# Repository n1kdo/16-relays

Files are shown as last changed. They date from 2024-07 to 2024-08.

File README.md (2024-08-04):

# 16-relays

This is a board that allows a Raspberry Pi Pico-W to control 16 SPST relays.

The original purpose is to provide better automation for a 2-in, 6-out remote antenna switch, but
it is built with extra capacity to allow a 2-in, 8-out remote switch as well.

## 3D image from KiCad
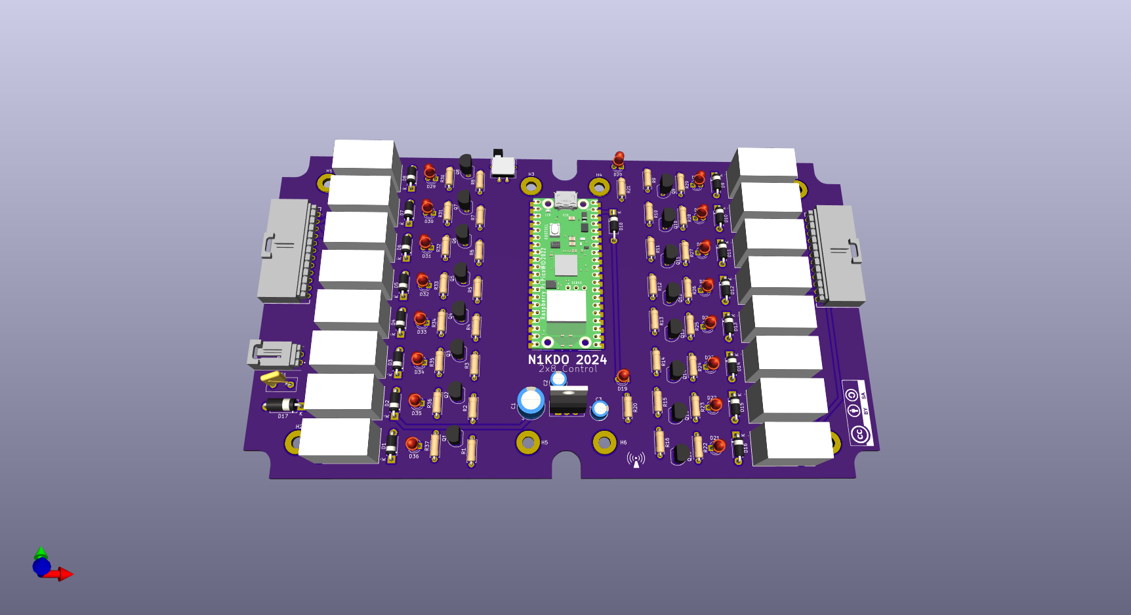
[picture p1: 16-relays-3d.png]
3d image


## Real World Image

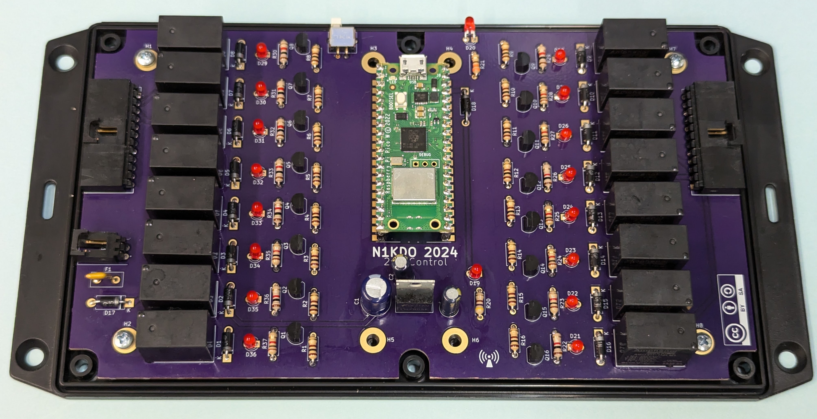
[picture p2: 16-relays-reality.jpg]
Real-World Image


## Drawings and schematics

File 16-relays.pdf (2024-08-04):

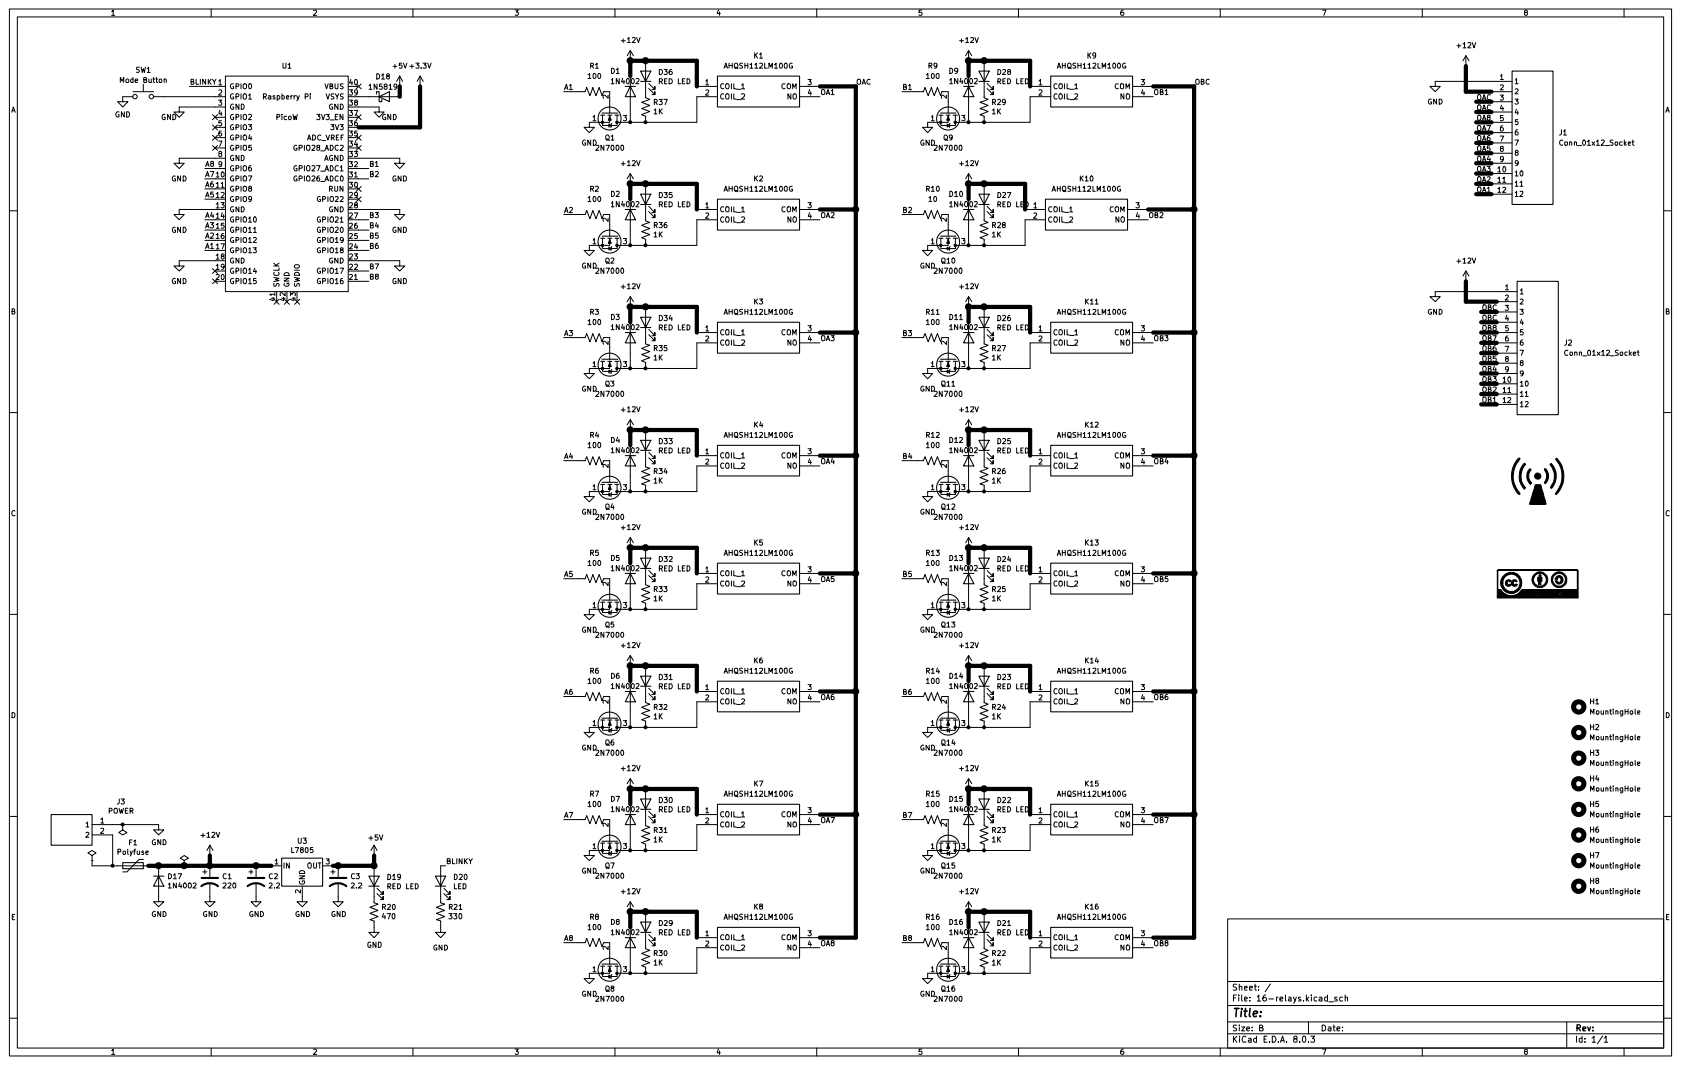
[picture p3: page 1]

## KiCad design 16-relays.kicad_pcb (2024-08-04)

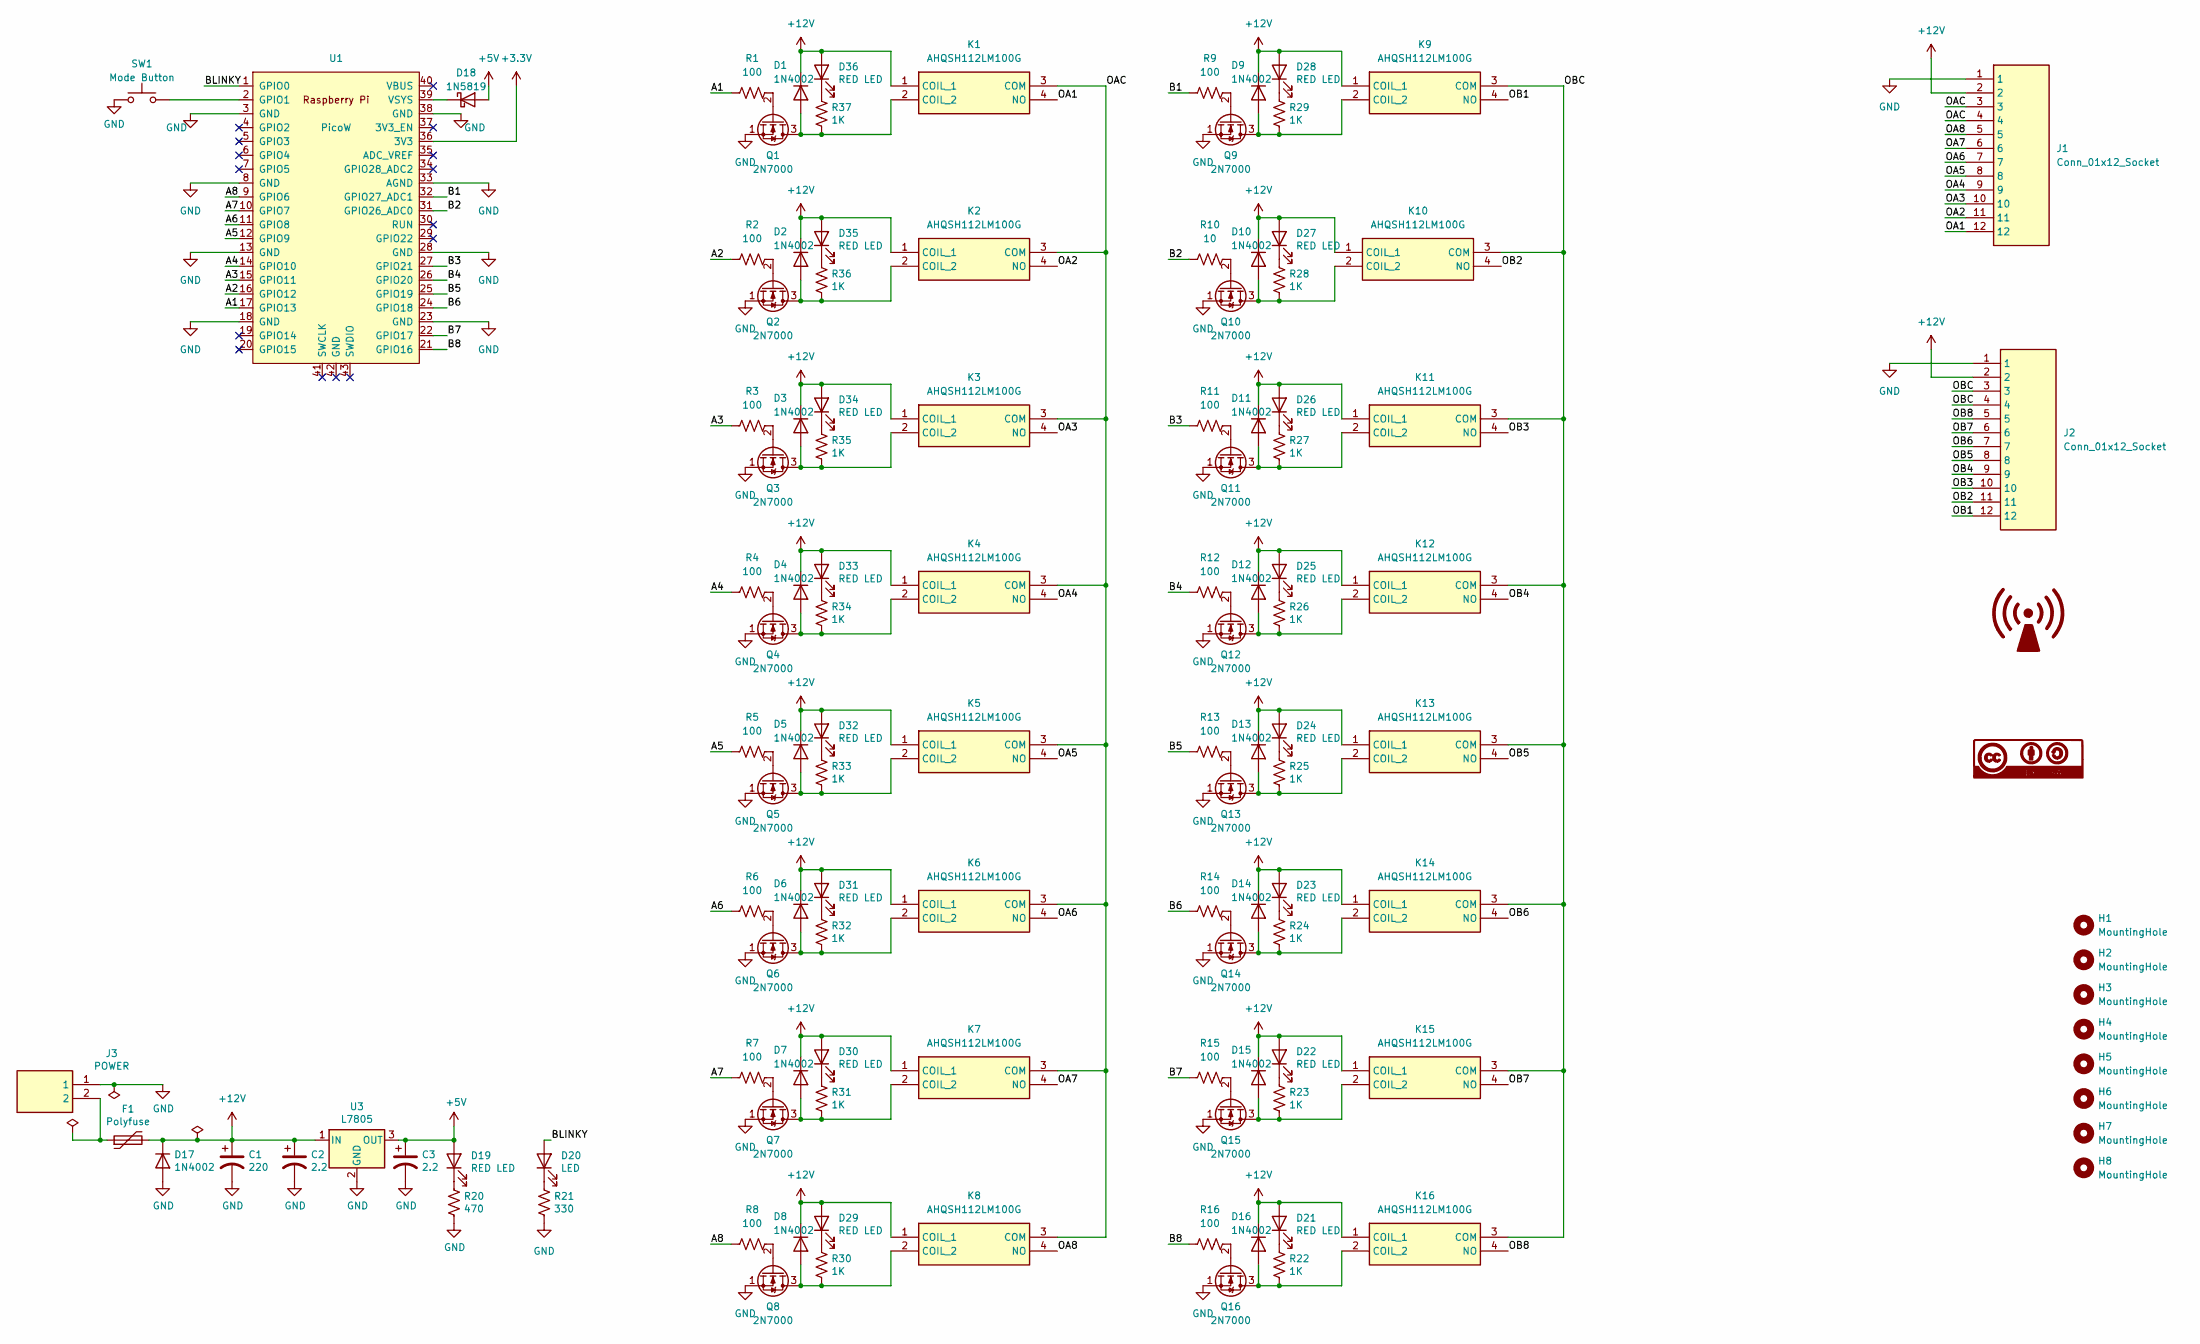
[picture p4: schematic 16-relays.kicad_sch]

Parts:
C1: 220; CP_Radial_D8.0mm_P3.50mm; Part ECA-1EM221
C2, C3: 2.2; CP_Radial_D5.0mm_P2.50mm; Part EEU-FC1H2R2H
D1, D2, D3, D4, D5, D6, D7, D8, D9, D10, D11, D12, D13, D14, D15, D16: 1N4002; D_DO-41_SOD81_P7.62mm_Horizontal
D17: 1N4002; D_DO-15_P10.16mm_Horizontal; Part 1n4002
D18: 1N5819; D_DO-41_SOD81_P10.16mm_Horizontal
D19: RED LED; LED_D3.0mm
D20: LED; LED_D3.0mm
D21, D22, D23, D24, D25, D26, D27, D28, D29, D30, D31, D32, D33, D34, D35, D36: RED LED; LED_D3.0mm; Part AP2012HD
F1: Polyfuse; RUEF090; Part 30R090UU
H1, H2, H3, H4, H5, H6, H7, H8: MountingHole; MountingHole_3.5mm_Pad
J1, J2: Conn_01x12_Socket; 705530116; Mouser Part Number 538-70553-0116
J3: POWER; 705530001; Part 26-60-4020; Mouser Part Number 538-70553-0001
K1, K2, K3, K4, K5, K6, K7, K8, K9, K10, K11, K12, K13, K14, K15, K16: AHQSH112LM100G; AHQSH112LM112G; Mouser Part Number 523-AHQSH105LM100G
Q1, Q2, Q3, Q4, Q5, Q6, Q7, Q8, Q9, Q10, Q11, Q12, Q13, Q14, Q15, Q16: 2N7000; TO-92_Inline
R1, R2, R3, R4, R5, R6, R7, R8, R9, R11, R12, R13, R14, R15, R16: 100; R_Axial_DIN0207_L6.3mm_D2.5mm_P7.62mm_Horizontal
R10: 10; R_Axial_DIN0207_L6.3mm_D2.5mm_P7.62mm_Horizontal
R20: 470; R_Axial_DIN0207_L6.3mm_D2.5mm_P7.62mm_Horizontal; Part ERJ-6GEYJ471V
R21: 330; R_Axial_DIN0207_L6.3mm_D2.5mm_P7.62mm_Horizontal; Part ERJ-6GEYJ471V
R22, R23, R24, R25, R26, R27, R28, R29, R30, R31, R32, R33, R34, R35, R36, R37: 1K; R_Axial_DIN0207_L6.3mm_D2.5mm_P7.62mm_Horizontal; Part ERJ-6GEYJ471V
SW1: Mode Button; GB215AHB; part GB215AH
U1: PicoW; RPi_PicoW_SMD_TH
U3: L7805; TO-220-3_Vertical; Part L7805CDT-TR

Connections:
+3.3V: U1.36 (3V3)
+5V: C3.1, D18.2 (A), D19.2 (A), U3.3 (OUT)
+12V: C1.1, C2.1, D1.1 (K), D2.1 (K), D3.1 (K), D4.1 (K), D5.1 (K), D6.1 (K), D7.1 (K), D8.1 (K), D9.1 (K), D10.1 (K), D11.1 (K), D12.1 (K), D13.1 (K), D14.1 (K), D15.1 (K), D16.1 (K), D17.1 (K), D21.2 (A), D22.2 (A), D23.2 (A), D24.2 (A), D25.2 (A), D26.2 (A), D27.2 (A), D28.2 (A), D29.2 (A), D30.2 (A), D31.2 (A), D32.2 (A), D33.2 (A), D34.2 (A), D35.2 (A), D36.2 (A), F1.2, J1.2, J2.2, K1.1 (COIL_1), K2.1 (COIL_1), K3.1 (COIL_1), K4.1 (COIL_1), K5.1 (COIL_1), K6.1 (COIL_1), K7.1 (COIL_1), K8.1 (COIL_1), K9.1 (COIL_1), K10.1 (COIL_1), K11.1 (COIL_1), K12.1 (COIL_1), K13.1 (COIL_1), K14.1 (COIL_1), K15.1 (COIL_1), K16.1 (COIL_1), U3.1 (IN)
/A1: R1.1, U1.17 (GPIO13)
/A2: R2.1, U1.16 (GPIO12)
/A3: R3.1, U1.15 (GPIO11)
/A4: R4.1, U1.14 (GPIO10)
/A5: R5.1, U1.12 (GPIO9)
/A6: R6.1, U1.11 (GPIO8)
/A7: R7.1, U1.10 (GPIO7)
/A8: R8.1, U1.9 (GPIO6)
/B1: R9.1, U1.32 (GPIO27_ADC1)
/B2: R10.1, U1.31 (GPIO26_ADC0)
/B3: R11.1, U1.27 (GPIO21)
/B4: R12.1, U1.26 (GPIO20)
/B5: R13.1, U1.25 (GPIO19)
/B6: R14.1, U1.24 (GPIO18)
/B7: R15.1, U1.22 (GPIO17)
/B8: R16.1, U1.21 (GPIO16)
/BLINKY: D20.2 (A), U1.1 (GPIO0)
/OA1: J1.12, K1.4 (NO)
/OA2: J1.11, K2.4 (NO)
/OA3: J1.10, K3.4 (NO)
/OA4: J1.9, K4.4 (NO)
/OA5: J1.8, K5.4 (NO)
/OA6: J1.7, K6.4 (NO)
/OA7: J1.6, K7.4 (NO)
/OA8: J1.5, K8.4 (NO)
/OAC: J1.3, J1.4, K1.3 (COM), K2.3 (COM), K3.3 (COM), K4.3 (COM), K5.3 (COM), K6.3 (COM), K7.3 (COM), K8.3 (COM)
/OB1: J2.12, K9.4 (NO)
/OB2: J2.11, K10.4 (NO)
/OB3: J2.10, K11.4 (NO)
/OB4: J2.9, K12.4 (NO)
/OB5: J2.8, K13.4 (NO)
/OB6: J2.7, K14.4 (NO)
/OB7: J2.6, K15.4 (NO)
/OB8: J2.5, K16.4 (NO)
/OBC: J2.3, J2.4, K9.3 (COM), K10.3 (COM), K11.3 (COM), K12.3 (COM), K13.3 (COM), K14.3 (COM), K15.3 (COM), K16.3 (COM)
GND: C1.2, C2.2, C3.2, D17.2 (A), J1.1, J2.1, J3.1, Q1.1 (S), Q2.1 (S), Q3.1 (S), Q4.1 (S), Q5.1 (S), Q6.1 (S), Q7.1 (S), Q8.1 (S), Q9.1 (S), Q10.1 (S), Q11.1 (S), Q12.1 (S), Q13.1 (S), Q14.1 (S), Q15.1 (S), Q16.1 (S), R20.2, R21.2, SW1.1, U1.3 (GND), U1.8 (GND), U1.13 (GND), U1.18 (GND), U1.23 (GND), U1.28 (GND), U1.33 (AGND), U1.38 (GND), U3.2 (GND)
unnamed: D1.2 (A), K1.2 (COIL_2), Q1.3 (D), R37.2
unnamed: D2.2 (A), K2.2 (COIL_2), Q2.3 (D), R36.2
unnamed: D3.2 (A), K3.2 (COIL_2), Q3.3 (D), R35.2
unnamed: D4.2 (A), K4.2 (COIL_2), Q4.3 (D), R34.2
unnamed: D5.2 (A), K5.2 (COIL_2), Q5.3 (D), R33.2
unnamed: D6.2 (A), K6.2 (COIL_2), Q6.3 (D), R32.2
unnamed: D7.2 (A), K7.2 (COIL_2), Q7.3 (D), R31.2
unnamed: D8.2 (A), K8.2 (COIL_2), Q8.3 (D), R30.2
unnamed: D9.2 (A), K9.2 (COIL_2), Q9.3 (D), R29.2
unnamed: D10.2 (A), K10.2 (COIL_2), Q10.3 (D), R28.2
unnamed: D11.2 (A), K11.2 (COIL_2), Q11.3 (D), R27.2
unnamed: D12.2 (A), K12.2 (COIL_2), Q12.3 (D), R26.2
unnamed: D13.2 (A), K13.2 (COIL_2), Q13.3 (D), R25.2
unnamed: D14.2 (A), K14.2 (COIL_2), Q14.3 (D), R24.2
unnamed: D15.2 (A), K15.2 (COIL_2), Q15.3 (D), R23.2
unnamed: D16.2 (A), K16.2 (COIL_2), Q16.3 (D), R22.2
unnamed: D18.1 (K), U1.39 (VSYS)
unnamed: D19.1 (K), R20.1
unnamed: D20.1 (K), R21.1
unnamed: D21.1 (K), R22.1
unnamed: D22.1 (K), R23.1
unnamed: D23.1 (K), R24.1
unnamed: D24.1 (K), R25.1
unnamed: D25.1 (K), R26.1
unnamed: D26.1 (K), R27.1
unnamed: D27.1 (K), R28.1
unnamed: D28.1 (K), R29.1
unnamed: D29.1 (K), R30.1
unnamed: D30.1 (K), R31.1
unnamed: D31.1 (K), R32.1
unnamed: D32.1 (K), R33.1
unnamed: D33.1 (K), R34.1
unnamed: D34.1 (K), R35.1
unnamed: D35.1 (K), R36.1
unnamed: D36.1 (K), R37.1
unnamed: F1.1, J3.2
unnamed: Q1.2 (G), R1.2
unnamed: Q2.2 (G), R2.2
unnamed: Q3.2 (G), R3.2
unnamed: Q4.2 (G), R4.2
unnamed: Q5.2 (G), R5.2
unnamed: Q6.2 (G), R6.2
unnamed: Q7.2 (G), R7.2
unnamed: Q8.2 (G), R8.2
unnamed: Q9.2 (G), R9.2
unnamed: Q10.2 (G), R10.2
unnamed: Q11.2 (G), R11.2
unnamed: Q12.2 (G), R12.2
unnamed: Q13.2 (G), R13.2
unnamed: Q14.2 (G), R14.2
unnamed: Q15.2 (G), R15.2
unnamed: Q16.2 (G), R16.2
unnamed: SW1.2, U1.2 (GPIO1)

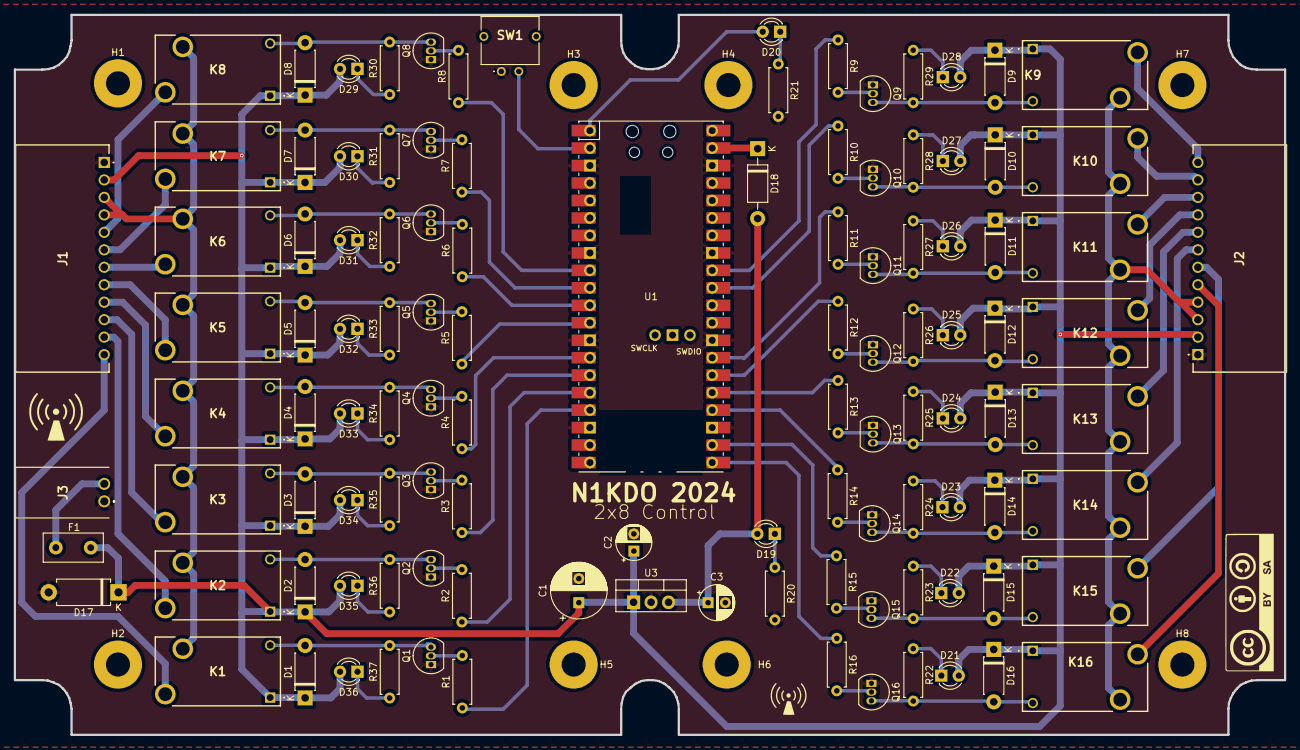
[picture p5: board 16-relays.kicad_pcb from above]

Board: 2 copper layers, 184.7 x 104.7 mm, 121 parts (0 on the bottom side), 91 nets.

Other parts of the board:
Ref**: Val**; CC-BY-SA

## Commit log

2024-07-14 schematic and pcb commit
    [16-relays.kicad_pcb, 16-relays.kicad_sch]
2024-07-14 add 3d image
    [16-relays.kicad_pcb]
2024-07-20 Update 16-relays.kicad_sch
    adjust LED current limiting resistors
    [16-relays.kicad_sch]
2024-08-04 add doc
    [16-relays.kicad_pcb]

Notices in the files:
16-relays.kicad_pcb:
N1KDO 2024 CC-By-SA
